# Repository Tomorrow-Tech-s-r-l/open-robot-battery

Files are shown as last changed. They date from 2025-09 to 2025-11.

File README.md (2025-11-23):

# ⚡ Open Robot Battery (ORB)

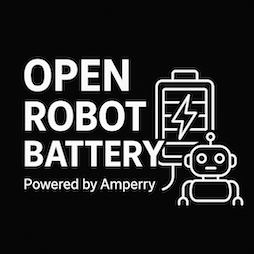
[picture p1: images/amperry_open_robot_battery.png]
Amperry Logo
 

*An open-source power delivery module for makers and robotics, powered by Amperry powerbanks.*

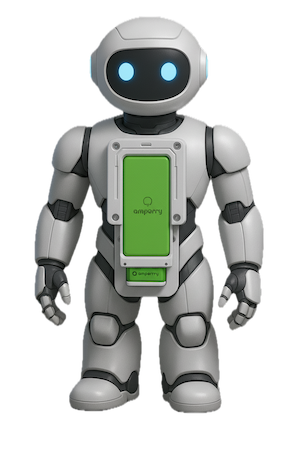
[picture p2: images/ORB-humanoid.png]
Humanoid Robot with ORB
  
*Humanoid robot powered by the ORB module.*

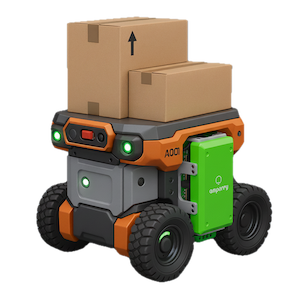
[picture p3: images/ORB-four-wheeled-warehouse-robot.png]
Four-wheeled Warehouse Robot with ORB
  
*Four-wheeled warehouse robot with ORB battery module.*

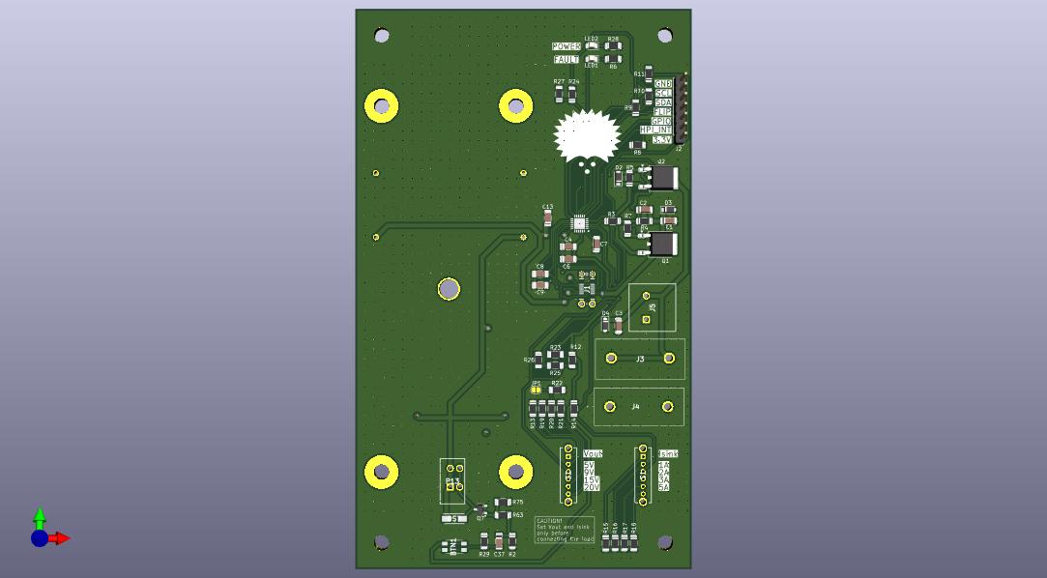
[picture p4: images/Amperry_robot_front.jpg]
Front PCB view
  
*Front PCB view.*

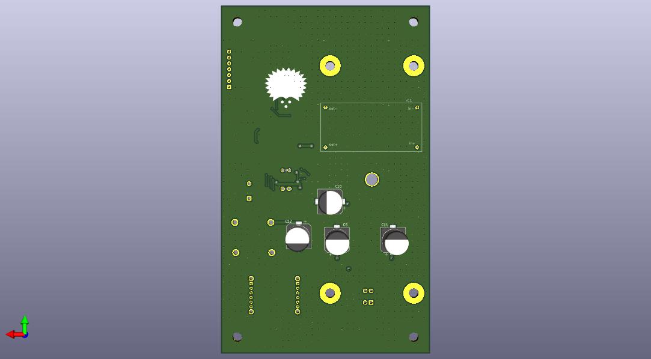
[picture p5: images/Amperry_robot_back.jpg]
Back PCB view
  
*Back PCB view.*

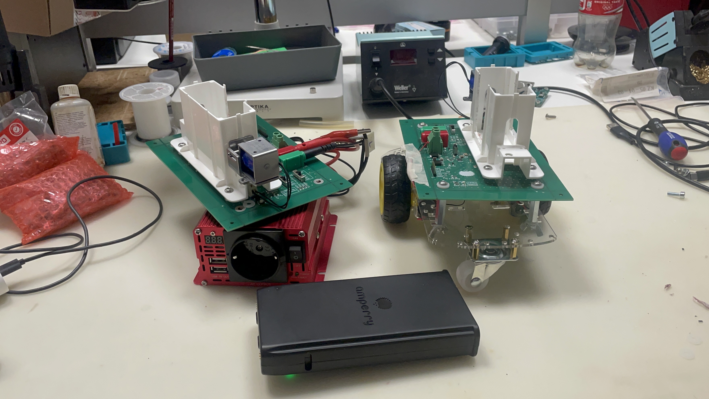
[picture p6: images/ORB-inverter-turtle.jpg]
ORB Inverter Turtle
  
*ORB inverter-turtle prototype with power inverter integration.*

ORB Development Kit  
*ORB development kit prototype for mobile robot applications.*

---

## 📖 Introduction

The **Open Robot Battery** (codename **ORB**) is an open-source hardware module designed to power up robots, IoT devices, drones, and prototypes.  

It works with **Amperry powerbanks**, which are charged inside Amperry stations, and provides makers, startups, and research labs with a flexible, safe, and modular way to bring portable energy into their projects.  

> ⚠️ **Important**: To use ORB you need an **Amperry-compatible powerbank**, which must be purchased together with an Amperry station. The ORB module is open-source, but the powerbanks remain proprietary.

---

## 🚀 Features

- ✅ Open hardware design for makers, startups, and research labs  
- ✅ Modular connection system (pogo pins, solenoid lock)  
- ✅ Flexible output: USB-C PD, robotics connectors (XT30/XT60), barrel jacks, etc.  
- ✅ Adaptable form factor – attach to robots, kiosks, IoT devices  
- ✅ Safe and tested with Amperry powerbanks  

---

## 🔌 How It Works
[ Amperry Station ] → [ Powerbank ] → [ ORB Module ] → [ Your Device ]

1. Powerbanks are charged inside the **Amperry station**.  
2. The charged powerbank is docked into the **ORB module**.  
3. ORB adapts the energy and delivers it to your device via your preferred connector.  

---

## 📦 Hardware Requirements

- **Required**: Amperry powerbank (purchase with a station from [Amperry](https://amperry.me))  
- Supported power levels:  
  - 5V (USB devices, IoT sensors)  
  - 12V (embedded boards, routers)  
  - 20V (robots, laptops, drones)  
- Connectors: USB-C PD, XT60, barrel jack, GPIO headers (customizable)  

---

## 🛠 Getting Started

1. Order an **Amperry powerbank + station**.  
2. Clone/download this repository.  
3. Access the **hardware files** in the `hardware/` folder:
   - Review the **schematics** (`hardware/schematics/LANDER_schematics.pdf`)
   - Check the **BOM** (`hardware/bom/LANDER_BOM.csv`) for component sourcing
   - Download **gerber files** (`hardware/gerber/LANDER-gerber-files.zip`) for PCB manufacturing
   - Use **CAD files** (`hardware/cad/LANDER_project_311025.zip`) for mechanical design and KiCad source files
4. Build or 3D-print the ORB module.  
5. Add the connectors your project requires.  
6. Plug in your powerbank and start powering your device.

## 🔧 Using with KiCad

The ORB project includes complete KiCad source files for both schematics and PCB layout. Follow these steps to open and work with the project in KiCad:

### Opening the KiCad Project

1. **Extract the CAD files**:
   ```bash
   cd hardware/cad
   unzip LANDER_project_311025.zip
   ```

2. **Open in KiCad**:
   - Launch KiCad (version 8.0 or later recommended)
   - Go to **File → Open Project**
   - Navigate to the extracted folder and open `Amperry_robot.kicad_pro`

3. **Project Structure**:
   The KiCad project contains:
   - `Amperry_robot.kicad_sch` - Main schematic file
   - `inputs_sheet.kicad_sch` - Input section schematic
   - `mech_conn_sheet.kicad_sch` - Mechanical connector section schematic
   - `Amperry_robot.kicad_pcb` - PCB layout file

### Viewing Schematics

- Click **Open Schematic** (or press `Ctrl+E`) to view the electrical schematics
- The project uses hierarchical sheets - navigate between sheets using the **Hierarchy Navigator** (press `Ctrl+H`)
- Use the **Properties** panel (press `E` on a component) to view component details

### Viewing PCB Layout

- Click **Open PCB Editor** (or press `Ctrl+P`) to view the PCB layout
- Use **3D Viewer** (press `Alt+3`) to see a 3D visualization of the board
- Switch between front and back layers using the layer selector

### Making Modifications

1. **Before making changes**, create a new branch or fork the repository
2. **Modify schematics** as needed:
   - Add/remove components
   - Adjust component values
   - Modify connections
3. **Update PCB layout** if schematic changes affect the board:
   - Run **Tools → Update PCB from Schematic** (or press `F8`) to sync changes
   - Adjust component placement and routing as needed
4. **Generate new Gerber files**:
   - Go to **File → Fabrication Outputs → Gerbers**
   - Select all layers and click **Generate Drill Files**
   - Export files for manufacturing

### Exporting for Manufacturing

1. **Generate Gerbers**:
   - File → Fabrication Outputs → Gerbers
   - Ensure all layers are selected (F.Cu, B.Cu, F.Silkscreen, B.Silkscreen, F.Mask, B.Mask, Edge.Cuts)
   - Generate drill files (PTH and NPTH)

2. **Generate BOM**:
   - File → Fabrication Outputs → BOM
   - Export as CSV or use the built-in BOM tool

3. **Create 3D Model**:
   - File → Export → STEP
   - Useful for mechanical integration

### Tips for Contributors

- Always run **Electrical Rules Check** (ERC) before committing changes (Tools → ERC)
- Run **Design Rules Check** (DRC) for PCB changes (Tools → DRC)
- Keep component libraries updated
- Document any significant changes in commit messages
- Test schematic changes by regenerating and reviewing the PDF export

## 📋 Documentation

- **[Technical Manual](MANUAL.md)** - Complete technical documentation including assembly instructions, safety warnings, and usage guidelines
- **[Hardware Files](hardware/)** - All hardware design files organized by type:
  - **[Schematics](hardware/schematics/)** - Electrical schematics in PDF format
  - **[Gerber Files](hardware/gerber/)** - PCB manufacturing files
  - **[Bill of Materials](hardware/bom/)** - Complete BOM in CSV format
  - **[CAD Files](hardware/cad/)** - KiCad source files (.kicad_sch, .kicad_pcb), 3D mechanical models (STEP), and Gerber files
  - **[Images](images/)** - Project images and diagrams  

---

## 💡 Example Use Cases

- 🤖 Robotics platforms and mobile robots  
- 🚁 Drones and UAVs  
- 🌐 IoT devices and field instruments  
- 🏫 University labs and prototyping kits  
- 🖥 Portable kiosks and installations  

---

## 📜 License & Usage Rules

- ORB is released as **open-source hardware** (license: [CC BY-NC-SA]).  
- **Restrictions**:  
  - The **Amperry powerbank hardware is proprietary** and must be purchased from Amperry.  
  - Usage in **powerbank rental systems** is exclusive to Amperry.  
  - Usage in **defense or weapons applications** requires prior approval and a special license.  

- For complete license details, see [LICENSE.md](LICENSE.md).
---

## 🤝 Contributing

We welcome contributions from the community! Here's how you can help improve the Open Robot Battery project.

### How to Contribute

1. **Report Issues**:
   - Found a bug or have a suggestion? Open an issue on GitHub
   - Include as much detail as possible: steps to reproduce, expected vs actual behavior, relevant files

2. **Improve Documentation**:
   - Fix typos or clarify instructions
   - Add missing information or examples
   - Translate documentation to other languages
   - Improve code comments and docstrings

3. **Hardware Improvements**:
   - **KiCad Project**: Modify schematics or PCB layout using the provided KiCad files
     - Extract the CAD files from `hardware/cad/LANDER_project_REV_DATE.zip` to work on them
     - Make changes in a new branch
     - Run ERC (Electrical Rules Check) and DRC (Design Rules Check) before submitting
     - Export updated Gerber files and update the repository
     - **Before committing**: Re-zip the CAD project folder and delete the unzipped folder
       ```bash
       cd hardware/cad
       zip -r LANDER_project_REV_DATE.zip [extracted_folder_name]/
       rm -rf [extracted_folder_name]/
       ```
     - Only commit the `.zip` file, not the extracted project files
     - This keeps the repository clean and prevents versioning conflicts with KiCad temporary files
   - **Mechanical Design**: Improve casing, mounting options, or add new connector configurations
   - **Component Selection**: Suggest better components or alternatives in the BOM

4. **Submit Pull Requests**:
   - Fork the repository
   - Create a feature branch (`git checkout -b feature/amazing-feature`)
   - Make your changes and test thoroughly
   - Commit with clear messages (`git commit -m 'Add amazing feature'`)
   - Push to your fork (`git push origin feature/amazing-feature`)
   - Open a Pull Request with a clear description of changes

### Contribution Guidelines

- **Code/Hardware Changes**:
  - Follow existing project structure and naming conventions
  - Ensure all tests pass (if applicable)
  - Update documentation for any new features
  - Run ERC/DRC checks for KiCad changes

- **Documentation**:
  - Use clear, concise language
  - Include examples where helpful
  - Update the README if adding new features

- **Pull Request Process**:
  - Keep PRs focused on a single feature or fix
  - Reference related issues in your PR description
  - Be responsive to feedback and requested changes

### Areas Where We Need Help

- 🐛 **Bug Fixes**: Test the design and report any issues
- 🔌 **New Connectors**: Add support for additional connector types
- 📐 **Mechanical Designs**: Improve casing, mounting solutions, or create 3D printable parts
- 🌍 **Translations**: Translate documentation to other languages
- 📚 **Examples**: Create example projects and use cases
- 🔬 **Testing**: Test designs with different powerbanks and report results

### Share Your Projects

We love seeing what people build with ORB! Share your projects:
- Open an issue with photos and description
- Tag us on social media
- Contribute to the gallery section

Thank you for contributing to open-source hardware! 🎉  

---

## 🌍 Community & Contact

- 🌐 Website: [https://tomorrowtech.it/open-robot-battery.html](https://amperry.me)  
- ✉️ Email: sviluppo@tomorrowtech.it  

---

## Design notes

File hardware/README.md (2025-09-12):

# Hardware Design Files

This folder contains all the hardware design files for the **LANDER** module (Open Robot Battery), organized for easy access and reproduction.

## 📁 Folder Structure

```
hardware/
├── schematics/          # Electrical schematics and circuit diagrams
├── gerber/             # PCB manufacturing files
├── bom/                # Bill of Materials (component lists)
├── cad/                # 3D mechanical models and CAD files
└── images/             # Project images and diagrams
```

## 📋 File Types

### Schematics (`schematics/`)
- **LANDER-schematics.pdf** - Complete electrical circuit diagrams for the LANDER module
- **Source files** - Original schematic files (KiCad, Altium, etc.)

### Manufacturing Files (`gerber/`)
- **LANDER-gerber-files.zip** - PCB manufacturing files for LANDER module fabrication
- **Drill files** - Hole drilling specifications
- **Panel files** - Multi-board panels for automated assembly

### Bill of Materials (`bom/`)
- **LANDER-BOM.xlsx** - Complete component list with part numbers and suppliers
- **LANDER-BOM.csv** - Machine-readable format for import into other systems

### CAD Files (`cad/`)
- **LANDER-CAD-files.zip** - Complete mechanical design package
- **3D Models** - Mechanical design files (STEP, STL)
- **Source CAD** - Original design files (SolidWorks, Fusion 360, etc.)

### Images (`images/`)
- **Project photos** - Assembly and usage images
- **Diagrams** - Technical illustrations and block diagrams

## 🛠 Manufacturing Notes

- **PCB Thickness**: 1.6mm
- **Copper Weight**: 1oz
- **Surface Finish**: HASL or ENIG recommended
- **Solder Mask**: Green (standard)
- **Silkscreen**: White

## 📦 Component Sourcing

All components in the BOM are selected from major electronics distributors for:
- Easy sourcing and availability
- Competitive pricing
- Quality assurance
- Lead time reliability

## ⚠️ Important Notes

- This is a **proof-of-concept** design for laboratory use only
- Not certified for commercial applications
- Follow all safety guidelines in the technical manual
- Use proper ESD precautions when handling components

## 🔗 Related Documentation

- [Technical Manual](../MANUAL.md) - Complete assembly and usage instructions
- [Main README](../README.md) - Project overview and getting started guide

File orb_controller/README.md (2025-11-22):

# ORB Controller ROS Package

## Overview

The `orb_controller` package provides a ROS interface for controlling the Infineon EZ-PD BCR (CYPD3177) USB Type-C Port Controller via I2C. This package enables monitoring and control of USB Power Delivery (PD) negotiation for robotic battery management systems.

## Features

- **I2C Communication:** Direct hardware interface to EZ-PD BCR chip
- **Power Monitoring:** Real-time voltage, current, and power status
- **PD Control:** Request specific voltage profiles (5V, 9V, 12V, 15V, 20V)
- **Status Publishing:** Continuous monitoring via ROS topics
- **Service Interface:** On-demand control via ROS services
- **Safety Features:** Voltage/current limits and fault monitoring

## Hardware Requirements

- Infineon EZ-PD BCR (CYPD3177) chip
- I2C connection to host system
- USB Type-C connector with PD support
- Appropriate power source/sink capabilities

## Dependencies

### System Dependencies
```bash
sudo apt-get install -y \
    i2c-tools \
    libi2c-dev \
    python3-smbus
```

### ROS Dependencies
- ROS Noetic (or compatible version)
- roscpp
- std_msgs
- message_generation
- message_runtime

## Installation

1. Clone the repository to your catkin workspace:
```bash
cd ~/catkin_ws/src
git clone <repository-url>
```

2. Build the package:
```bash
cd ~/catkin_ws
catkin_make
source devel/setup.bash
```

3. Configure I2C permissions (if needed):
```bash
sudo usermod -a -G i2c $USER
# Log out and back in for changes to take effect
```

## Usage

### Launch the Controller Node

Basic launch:
```bash
roslaunch orb_controller orb_controller.launch
```

With custom parameters:
```bash
roslaunch orb_controller orb_controller.launch i2c_bus:=1 i2c_address:=0x08 publish_rate:=10.0
```

### Published Topics

- `/orb/power_status` ([orb_controller/PowerStatus])
  - Real-time power measurements
  - Published at configured rate (default: 10 Hz)

- `/orb/pd_status` ([orb_controller/PDStatus])
  - USB-C PD negotiation status
  - Published at configured rate (default: 10 Hz)

### Services

- `/orb_controller/get_status` ([orb_controller/GetStatus])
  - Get current voltage, current, and PD status

- `/orb_controller/set_voltage_current` ([orb_controller/SetVoltageCurrent])
  - Request specific voltage and current limits

- `/orb_controller/request_pd_role` ([orb_controller/RequestPDRole])
  - Request specific PD profile (1-5)

### Parameters

Configuration parameters can be set in `config/orb_controller_params.yaml`:

- `i2c_bus`: I2C bus number (default: 1)
- `i2c_address`: I2C device address (default: 0x08)
- `publish_rate`: Status publishing rate in Hz (default: 10.0)
- `max_voltage_mv`: Maximum allowed voltage in mV (default: 20000)
- `max_current_ma`: Maximum allowed current in mA (default: 5000)

## Testing

### ROS Test Script
```bash
rosrun orb_controller test_orb_controller.py
```

Monitor mode:
```bash
rosrun orb_controller test_orb_controller.py monitor
```

### Direct I2C Test (bypasses ROS)
```bash
# Basic test
python3 scripts/test_i2c_direct.py

# Custom bus and address
python3 scripts/test_i2c_direct.py --bus 1 --addr 0x08

# Scan all registers
python3 scripts/test_i2c_direct.py --scan

# Monitor for 30 seconds
python3 scripts/test_i2c_direct.py --monitor 30
```

## Examples

### Request 12V Profile
```bash
rosservice call /orb_controller/request_pd_role "profile: 3"
```

### Set Specific Voltage and Current
```bash
rosservice call /orb_controller/set_voltage_current "voltage_mv: 9000
current_ma: 2000"
```

### Get Current Status
```bash
rosservice call /orb_controller/get_status
```

### Monitor Power Status
```bash
rostopic echo /orb/power_status
```

## Message Definitions

### PowerStatus.msg
```
std_msgs/Header header
uint16 voltage_mv        # Voltage in millivolts
uint16 current_ma        # Current in milliamps
uint32 power_mw          # Power in milliwatts
bool pd_active           # PD negotiation active
uint8 pd_profile         # Current PD profile (1-5)
```

### PDStatus.msg
```
std_msgs/Header header
uint8 pd_status_raw      # Raw PD status byte
uint8 port_status_raw    # Raw port status byte
bool type_c_connected    # USB-C cable connected
bool pd_contract_active  # PD contract established
uint8 current_profile    # Active profile number
uint16 negotiated_voltage_mv  # Negotiated voltage
uint16 negotiated_current_ma  # Negotiated current
```

## Troubleshooting

### I2C Connection Issues
```bash
# Check if I2C device is detected
i2cdetect -y 1

# Verify I2C permissions
ls -l /dev/i2c-*

# Test I2C communication
i2cget -y 1 0x08 0x00
```

### Node Not Starting
- Check ROS master is running: `roscore`
- Verify I2C device permissions
- Check correct I2C bus and address in parameters
- Review log output: `rosrun orb_controller orb_controller_node`

### No Power Delivery
- Verify USB-C cable supports PD
- Check power source capabilities
- Monitor PD status: `rostopic echo /orb/pd_status`
- Review fault status in logs

## Register Documentation

See [docs/REGISTER_MAP.md](docs/REGISTER_MAP.md) for detailed register descriptions and bit definitions.

**Important:** The register addresses in this package are based on typical EZ-PD BCR implementations. You must verify these with your specific CYPD3177 datasheet and update the following files accordingly:
- `include/orb_controller/ezpd_bcr_i2c.h` - Register address definitions
- `src/ezpd_bcr_i2c.cpp` - Register access implementations
- `src/orb_controller_node.cpp` - Status bit interpretations

## Safety Notes

⚠️ **WARNING:** Improper voltage/current settings can damage connected devices.

- Always verify device voltage tolerances before changing profiles
- Monitor fault status regularly
- Implement appropriate error handling in production code
- Test with current-limited supplies during development
- Never exceed maximum ratings specified in datasheets

## License

This package is released under the CC-BY-NC-SA license as specified in the package.xml file.

## Support

For issues and questions, please contact: sviluppo@tomorrowtech.it

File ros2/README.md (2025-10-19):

# ORB ROS 2 Workspace

This directory contains the ROS 2 workspace that hosts software support for the Open Robot Battery (ORB).

## Packages

- `orb_i2c_interfaces`: Service definitions shared across the I2C stack.
- `orb_i2c_support`: Python implementation of the I2C management node with a pluggable backend, including both a simulation layer and a driver for the Infineon EZ-PD BCR USB-C sink controller.

## Building

```bash
cd ros2
colcon build
source install/setup.bash
```

> If you only want to build the packages added here, append `--packages-up-to orb_i2c_support`.

## Running the I2C manager

```bash
ros2 launch orb_i2c_support i2c_manager.launch.py
```

By default the node runs in simulation mode. All transactions are served from an in-memory backend that mimics a trivial I2C device.

### Useful Parameters

| Parameter | Default | Description |
|---|---|---|
| `backend` | `simulation` | Backend name registered in `orb_i2c_support.backend_factory`. |
| `bus_id` | `i2c-1` | Logical identifier for the I2C bus; forwarded to the backend. |
| `backend_plugin` | *empty* | Optional `module:ClassName` string to load a custom backend. |
| `backend_configuration` | `{}` | JSON configuration passed to the backend. |
| `status_interval_sec` | `1.0` | Interval in seconds for status publication on `orb_i2c/status`. |

Example launch overriding the backend configuration:

```bash
ros2 launch orb_i2c_support i2c_manager.launch.py \
  backend_configuration:='{"devices": [{"address": 16, "memory": [1, 2, 3]}]}'
```

### Calling the service

Once the node is running:

```bash
ros2 service call /i2c/transaction orb_i2c_interfaces/srv/I2CTransaction \
  "{address: 16, write_data: [170, 187], read_length: 4, timeout: 0.1}"
```

The response will contain the simulated read buffer. When the real hardware backend becomes available, drop it in as a plugin and reuse the same service interface.

### Using the EZ-PD BCR backend

The Infineon EZ-PD BCR controller exposes its register map over I2C. The provided backend wraps the Linux `smbus2` stack to perform combined write/read transactions and optional power-on configuration sequences.

```bash
ros2 launch orb_i2c_support i2c_manager.launch.py \
  backend:=ez_pd_bcr \
  bus_id:=/dev/i2c-1 \
  backend_configuration:='{
    "default_address": 8,
    "init_sequence": [
      {"write_data": [0x00, 0x08]},  # Example: pull default register map
      {"write_data": [0x06, 0x01], "delay_ms": 5}
    ]
  }'
```

- `default_address` (optional) overrides the default 7-bit address (`0x08` in the datasheet).
- `init_sequence` (optional) allows writing configuration registers at launch. Each entry contains `write_data` (first byte is treated as the register offset) and an optional `delay_ms` for settling time between writes.

Typical tasks enabled by this backend:
- Read the status registers that report VBUS negotiation state, CC pin status, and fault indicators.
- Update configuration registers to adjust PDO selection, discharge behavior, or the sink power profile.
- Trigger firmware utilities such as soft resets or load complete configuration templates as documented in the datasheet.

Example register read (fetch the Status Register 1 at offset `0x05`):

```bash
ros2 service call /i2c/transaction orb_i2c_interfaces/srv/I2CTransaction \
  "{address: 8, write_data: [0x05], read_length: 1, timeout: 0.1}"
```

The first byte in `write_data` is interpreted by the controller as the register pointer; the returned byte shows the live status flags defined in section 6.3 of the EZ-PD BCR datasheet.

### Standalone Raspberry Pi smoke test

If you want to validate the hardware before running ROS:

```bash
pip install smbus2
python3 ros2/scripts/raspi_ez_pd_demo.py
```

The script opens `/dev/i2c-1`, reads Status Register 1 once per second, and prints the bit field as a binary string. A changing value indicates the Pi can reach the EZ-PD BCR device over the I²C bus.

## Tests

Run the unit tests with:

```bash
colcon test --packages-select orb_i2c_support
```

> The test suite depends on `pytest`. Install it in your environment (e.g., `pip install pytest`) if it is not already available.

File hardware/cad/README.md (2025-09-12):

# CAD Files

This folder contains the mechanical design files for the Open Robot Battery (LANDER) project.

## Files

- `LANDER-CAD-files.zip` - Complete CAD package containing 3D mechanical models and source files for the LANDER module
- `LANDER-mechanical.step` - 3D mechanical model in STEP format [TODO]
- `LANDER-mechanical.stl` - 3D printable files for prototyping [TODO]

## Mechanical Features

- Powerbank docking mechanism
- Spring ejector system
- Solenoid mounting points
- Connector mounting areas
- Heat dissipation considerations

## 3D Printing

STL files are provided for rapid prototyping and testing of mechanical components.

> **Note**: Replace this README with actual CAD files when available.

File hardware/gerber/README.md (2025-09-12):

# Gerber Files

This folder contains the manufacturing files for the Open Robot Battery (LANDER) PCB.

## Files

- `LANDER-gerber-files.zip` - Complete gerber file package for LANDER module PCB manufacturing

## Manufacturing Notes

- Board thickness: 1.6mm
- Copper weight: 1oz
- Surface finish: HASL or ENIG (recommended)
- Solder mask: Green (standard)
- Silkscreen: White

## Panel Information

The gerber package includes both:
- Individual PCB files
- Panel files with V-score lines for automated assembly

> **Note**: Replace this README with actual gerber files when available.

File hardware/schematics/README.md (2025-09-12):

# Schematics

This folder contains the electrical schematics for the Open Robot Battery (LANDER) project.

## Files

- `LANDER-schematics.pdf` - Complete electrical schematics for the LANDER module in PDF format

## Schematic Overview

The main schematic includes:
- USB-C Power Delivery Controller (CYPD3177)
- Boost converter for solenoid power
- Powerbank mechanical docking system
- I2C interface connections
- Multiposition switches for voltage/current selection

> **Note**: Replace this README with actual schematic files when available.

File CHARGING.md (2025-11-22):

# Battery Charging Guide

## Overview

This guide explains the temporary procedure for charging the Open Robot Battery. **Note:** This is a temporary charging method. A proper charging circuit is currently being developed.

## Prerequisites

- Power supply capable of delivering 16.8V and 0.8A
- Access to the powerbank connector (requires unscrewing the powerbank)

## Charging Procedure

### Step 1: Access the Connector

1. **Unscrew the powerbank** to gain access to the internal connector.

### Step 2: Connect Power Supply

1. Connect your power supply to the battery connector.
2. **Set the power supply to:**
   - **Voltage:** 16.8V
   - **Current:** 0.8A

### Step 3: Charging

1. Once connected and configured, the battery will begin charging.
2. **Charging time:** Approximately 3 hours

### Step 4: Disconnect

1. After the charging cycle is complete, disconnect the power supply.
2. Reassemble the powerbank by screwing it back together.

## Important Notes

⚠️ **This is a temporary charging solution.** A dedicated charging circuit with proper power supply management is currently under development and will replace this manual procedure in the future.

## Safety Reminders

- Always ensure the power supply is set to the correct voltage (16.8V) and current (0.8A) before connecting.
- Do not exceed the specified voltage and current limits.
- Monitor the charging process and disconnect if any abnormalities are observed.

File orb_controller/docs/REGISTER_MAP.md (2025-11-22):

# EZ-PD BCR (CYPD3177) Register Map Documentation

## Overview
This document describes the I2C register map for the Infineon EZ-PD BCR (CYPD3177) USB Type-C Port Controller.

**NOTE:** The register addresses and bit definitions below are based on typical EZ-PD BCR implementations. 
You should verify these with the actual CYPD3177 datasheet for your specific chip revision.

## I2C Interface Details

- **Default I2C Address:** 0x08 (can be modified via ADDR pins)
- **I2C Speed:** Standard mode (100 kHz) or Fast mode (400 kHz)
- **Data Format:** Big-endian for multi-byte registers

## Register Map

### Device Information Registers (0x00-0x0F)

| Address | Register Name | Access | Description |
|---|---|---|---|
| 0x00 | DEVICE_ID | R | Device identification |
| 0x01 | DEVICE_MODE | R/W | Device operation mode |
| 0x02 | INTERRUPT_CLEAR | W | Clear interrupt flags |
| 0x03 | INTERRUPT_MASK | R/W | Interrupt enable mask |
| 0x04 | PD_STATUS | R | Power Delivery status |
| 0x05 | TYPE_C_STATUS | R | USB Type-C connection status |
| 0x06-0x07 | BUS_VOLTAGE | R | VBUS voltage (16-bit) |
| 0x08-0x09 | CURRENT_PDO | R | Current Power Data Object |
| 0x0A-0x0B | VOLTAGE_STATUS | R | Negotiated voltage (16-bit) |
| 0x0C-0x0D | CURRENT_STATUS | R | Negotiated current (16-bit) |
| 0x0E | POWER_STATUS | R | Power status summary |
| 0x0F | FAULT_STATUS | R | Fault status flags |

### Control Registers (0x10-0x1F)

| Address | Register Name | Access | Description |
|---|---|---|---|
| 0x10 | PD_CONTROL | R/W | PD control and profile selection |
| 0x11 | PORT_CONTROL | R/W | Port enable/disable control |
| 0x12 | VBUS_CONTROL | R/W | VBUS control settings |
| 0x13 | CURRENT_LIMIT | R/W | Current limit configuration |
| 0x14-0x15 | VOLTAGE_REQUEST | R/W | Requested voltage (16-bit) |
| 0x16-0x17 | CURRENT_REQUEST | R/W | Requested current (16-bit) |
| 0x18 | SINK_CONTROL | R/W | Sink operation control |
| 0x19 | SOURCE_CONTROL | R/W | Source operation control |
| 0x1A | CABLE_DETECT | R | Cable detection status |
| 0x1B-0x1F | RESERVED | - | Reserved for future use |

### PDO Configuration Registers (0x20-0x3F)

| Address | Register Name | Access | Description |
|---|---|---|---|
| 0x20-0x23 | SINK_PDO_1 | R/W | Sink PDO #1 (5V profile) |
| 0x24-0x27 | SINK_PDO_2 | R/W | Sink PDO #2 (9V profile) |
| 0x28-0x2B | SINK_PDO_3 | R/W | Sink PDO #3 (12V profile) |
| 0x2C-0x2F | SINK_PDO_4 | R/W | Sink PDO #4 (15V profile) |
| 0x30-0x33 | SINK_PDO_5 | R/W | Sink PDO #5 (20V profile) |
| 0x34-0x37 | SINK_PDO_6 | R/W | Sink PDO #6 (PPS profile) |
| 0x38-0x3F | RESERVED | - | Reserved |

## Register Bit Definitions

### PD_STATUS Register (0x04)

| Bit | Name | Description |
|-----|---|---|
| 7 | PD_READY | PD negotiation complete |
| 6 | CONTRACT_EXIST | Valid PD contract exists |
| 5 | EXPLICIT_CONTRACT | Explicit contract negotiated |
| 4 | DATA_ROLE | 0=UFP, 1=DFP |
| 3 | POWER_ROLE | 0=Sink, 1=Source |
| 2 | VCONN_SOURCE | Device is VCONN source |
| 1 | PD_ENABLED | PD messaging enabled |
| 0 | PD_CONNECTED | PD capable device connected |

### TYPE_C_STATUS Register (0x05)

| Bit | Name | Description |
|-----|---|---|
| 7:6 | ATTACH_STATE | 00=Unattached, 01=AttachWait, 10=Attached, 11=Debug |
| 5 | ORIENTATION | 0=CC1, 1=CC2 |
| 4 | VBUS_PRESENT | VBUS voltage detected |
| 3 | VBUS_VALID | VBUS voltage in valid range |
| 2 | VCONN_PRESENT | VCONN supplied to cable |
| 1 | CC_STATUS | CC line status |
| 0 | CONNECTED | Cable connected |

### PD_CONTROL Register (0x10)

| Bit | Name | Description |
|-----|---|---|
| 7:5 | RESERVED | Reserved |
| 4:0 | PROFILE_SELECT | Select PDO profile (1-5) |

### FAULT_STATUS Register (0x0F)

| Bit | Name | Description |
|-----|---|---|
| 7 | OCP | Over-current protection triggered |
| 6 | OVP | Over-voltage protection triggered |
| 5 | OTP | Over-temperature protection triggered |
| 4 | VBUS_SHORT | VBUS short circuit detected |
| 3 | VCONN_OCP | VCONN over-current |
| 2 | HARD_RESET | Hard reset occurred |
| 1 | SOFT_RESET | Soft reset occurred |
| 0 | GENERAL_FAULT | General fault condition |

## Voltage and Current Scaling

### Voltage Registers
- **Unit:** 50mV per LSB
- **Range:** 0-20V (0x0000-0x0190)
- **Example:** 0x64 = 100 * 50mV = 5000mV = 5V

### Current Registers
- **Unit:** 10mA per LSB for standard current
- **Unit:** 50mA per LSB for high current (>3A)
- **Range:** 0-5A (0x0000-0x01F4)
- **Example:** 0xC8 = 200 * 10mA = 2000mA = 2A

## Standard PDO Profiles

| Profile | Voltage | Max Current | Power |
|---|---|---|---|
| 1 | 5V | 3A | 15W |
| 2 | 9V | 3A | 27W |
| 3 | 12V | 3A | 36W |
| 4 | 15V | 3A | 45W |
| 5 | 20V | 5A | 100W |

## I2C Transaction Examples

### Read Voltage Status
```
Write: [0x0A]       // Register address
Read:  [MSB] [LSB]  // 16-bit voltage value
```

### Set PD Profile
```
Write: [0x10] [0x03]  // Write 0x03 to PD_CONTROL for 12V profile
```

### Read PD Status
```
Write: [0x04]       // Register address
Read:  [Status]     // 8-bit status value
```

## Notes

1. Always verify register addresses and bit definitions with the actual CYPD3177 datasheet
2. Some registers may require specific sequences or timing for proper operation
3. Writing to read-only registers will be ignored
4. Some control registers may require device to be in specific state
5. Multi-byte registers typically use big-endian format, but verify with datasheet

## Safety Considerations

- Always check voltage and current capabilities before requesting higher profiles
- Monitor fault status register regularly
- Implement proper error handling for I2C communication failures
- Use appropriate delays between configuration changes
- Verify cable and device capabilities before negotiating high power profiles

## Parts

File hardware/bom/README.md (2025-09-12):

# Bill of Materials (BOM)

This folder contains the Bill of Materials for the Open Robot Battery (LANDER) project.

## Files

- `LANDER-BOM.xlsx` - Complete Bill of Materials for the LANDER module in Excel format with part numbers, quantities, and suppliers

## Key Components

### Main Components
- **CYPD3177** - USB-C Power Delivery Controller
- **Boost Converter** - For solenoid power supply
- **Solenoid** - Powerbank ejection mechanism
- **USB-C Connector** - Power input/output
- **Multiposition Switches** - Voltage/current selection

### Passive Components
- Resistors and capacitors for power management
- Connectors and headers for I2C interface
- Mechanical components for powerbank docking

## Sourcing Notes

All components are selected from major electronics distributors for easy sourcing and availability.

> **Note**: Replace this README with actual BOM files when available.

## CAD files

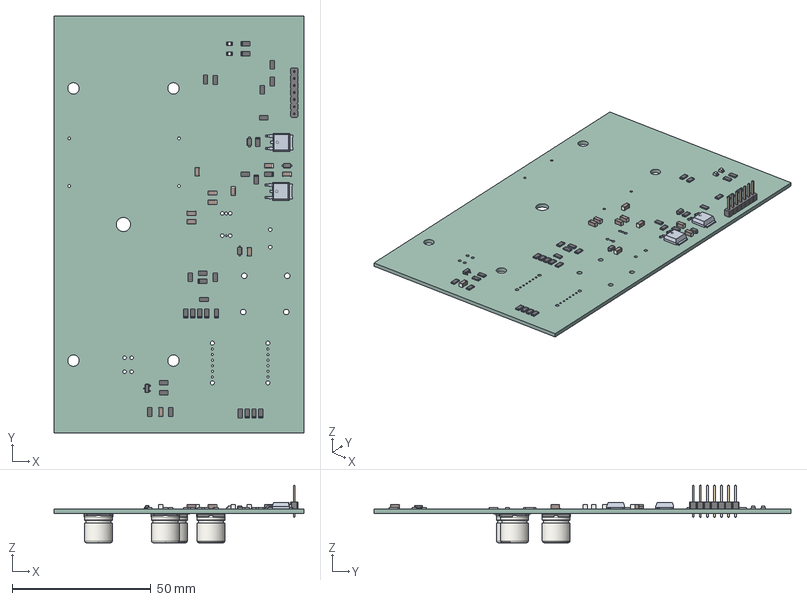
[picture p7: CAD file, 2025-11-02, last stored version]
hardware/cad/LANDER_project_311025/gerbers/Amperry_robot.step
90.0 x 150.0 x 20.7 mm
R_1206_3216Metric x 30
Amperry_robot 1.4.1 x 2
LED_0805_2012Metric x 2
D_SOD-123F x 3
C_1206_3216Metric x 10
PinHeader_1x07_P2.54mm_Vertical
SOT-23-3
CP_Elec_10x10.5 x 4
Amperry_robot_PCB

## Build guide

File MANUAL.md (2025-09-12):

# Open Robot Battery - Technical Manual

## Purpose of the Board

The purpose of this PCB is to provide a proof-of-concept (POC) charging solution for generic devices using a USB-C interface. The board is intended for laboratory and demonstration purposes, providing:

- Safe charging of low-power devices from a standardized USB-C port
- Flexibility to adapt to various input and output power requirements
- A compact design to fit within an existing powerbank slot

> **⚠️ Important**: This board is not certified for commercial use and is designed for internal testing, demonstration, and prototyping only.

## Main Function Blocks

| Block | Description | Key Components |
|---|---|---|
| **USB-C Power Delivery Controller** | This is the core of the board. It manages USB-C negotiation and ensures correct voltage/current delivery to the connected device. | CYPD3177, associated resistors and capacitors, controllable by the multiposition switches |
| **Boost Module** | Converts and regulates the input voltage from the powerbank to 24V for the coil solenoid | Boost converter |
| **Powerbank Mechanical Docking** | Provides mechanical and electrical connection for the powerbank | Spring ejector, coil solenoid, USB C connector* |
| **I2C Interface** | To access status and control register | Pin strip connection |

> *Only for the POC, the future release will be different

## How It Works

### Power Input
- The board receives voltage from the connected powerbank
- The board is designed to be compatible with the Amperry powerbank that supports USB-C PD up to 20V

### USB-C Negotiation
- The CYPD3177 acts as the USB-C controller
- The controller negotiates the required voltage/current with the powerbank

### Voltage/Current Regulation and Output Delivery
There are 2 multiposition switches (SW1 and SW2) that allow the user to select some resistor combinations that set the output voltage and current limit.

> **⚠️ Important**: The output voltage (V) and current limit (I) must be set through the switch before connecting the load. The mechanical switch can temporarily disconnect the resistive load when moving from one position to another; during this brief interval, the output voltage automatically rises to the maximum available voltage (20V). Connecting a load before setting V/I can damage the device.

### Powerbank Ejection
- The board contains a boost converter that raises the supply to 24V for the solenoid
- When the push-button is pressed, the solenoid coil is energized, pulling a plunger
- The mechanical spring then ejects the powerbank from its slot
- To ensure that the coil solenoid stays active only for a short time enough to unlock the powerbank (even if the button is pressed for a long time) there is an ad hoc RC filter
- The solenoid is de-energized after the ejection cycle

## Assembly Instructions

This project package includes two main items:
- **Individual PCB** – the proof-of-concept board for multidevice recharge
- **PCB Panel** – a larger panel containing multiple copies of the board, separated by V-score lines, designed to facilitate automatic component placement during production

### Hardware Files Location

All hardware design files are organized in the `hardware/` folder:
- **Schematics**: `hardware/schematics/LANDER-schematics.pdf`
- **Gerber Files**: `hardware/gerber/LANDER-gerber-files.zip`
- **Bill of Materials**: `hardware/bom/LANDER-BOM.xlsx`
- **CAD Files**: `hardware/cad/LANDER-CAD-files.zip`

### Component Assembly
- All components were selected from major electronics distributors for easy sourcing (see BOM in `hardware/bom/`)
- **Manual soldering**: Most components, including resistors, capacitors, connectors, and the boost converter, can be soldered by hand without specialized equipment
- **CYPD3177**: This IC requires careful soldering due to its fine pitch; automated reflow or precision soldering is recommended

### Assembly Steps
1. Detach the individual PCB from the V-scored panel along the designated lines
2. Populate components starting with the lowest profile parts (resistors, capacitors), followed by connectors and the boost converter
3. Place the CYPD3177 last, using appropriate soldering techniques to ensure proper alignment and connection
4. Inspect all solder joints for bridges or cold soldering, paying special attention to the USB-C controller and high-current paths

## Testing

1. Before connecting a load, set the output voltage and current using SW1 and SW2
2. Apply power from a compatible USB-C power source
3. Verify correct voltage at the output terminals with a multimeter
4. Test the powerbank ejection mechanism without a load first to ensure the solenoid operates correctly
5. Once verified, the board is ready for controlled laboratory use with target devices

## Safety Warnings

> **⚠️ Important**: This board is a proof-of-concept prototype intended for controlled laboratory use only. It is not certified for commercial or consumer applications.

### Electrical Safety

- **Voltage spikes**: When changing the output voltage/current with the switches, the board may briefly output the maximum available voltage (~20 V). Always set the desired V/I before connecting a load
- **Risk of damage**: Connecting devices before setting the correct voltage/current may damage the load or the board
- **High-current paths**: The solenoid and boost converter can draw significant current. Avoid touching exposed conductors during operation
- **Short circuits**: Do not short the output terminals. This can damage the board and connected power sources

### Mechanical Safety

- The board contains a spring-eject mechanism and solenoid. Do not place fingers or objects near the moving parts during testing to prevent pinching or injury
- Ensure the board is securely mounted on a stable surface during testing

### Component Handling

- The CYPD3177 and other ICs are sensitive to ESD. Use proper anti-static precautions (wrist strap, ESD mat) when handling
- Soldering should be performed in a well-ventilated area. Avoid inhaling solder fumes

### Usage Limitations

- The board is designed for low-power devices only. Do not connect high-power or commercial devices
- **Environmental conditions**: Operate only in dry, controlled laboratory environments. Avoid exposure to water, high humidity, or uncontrolled loads
- No CE, EMC, or other certifications are included. Users are responsible for ensuring safe lab practices

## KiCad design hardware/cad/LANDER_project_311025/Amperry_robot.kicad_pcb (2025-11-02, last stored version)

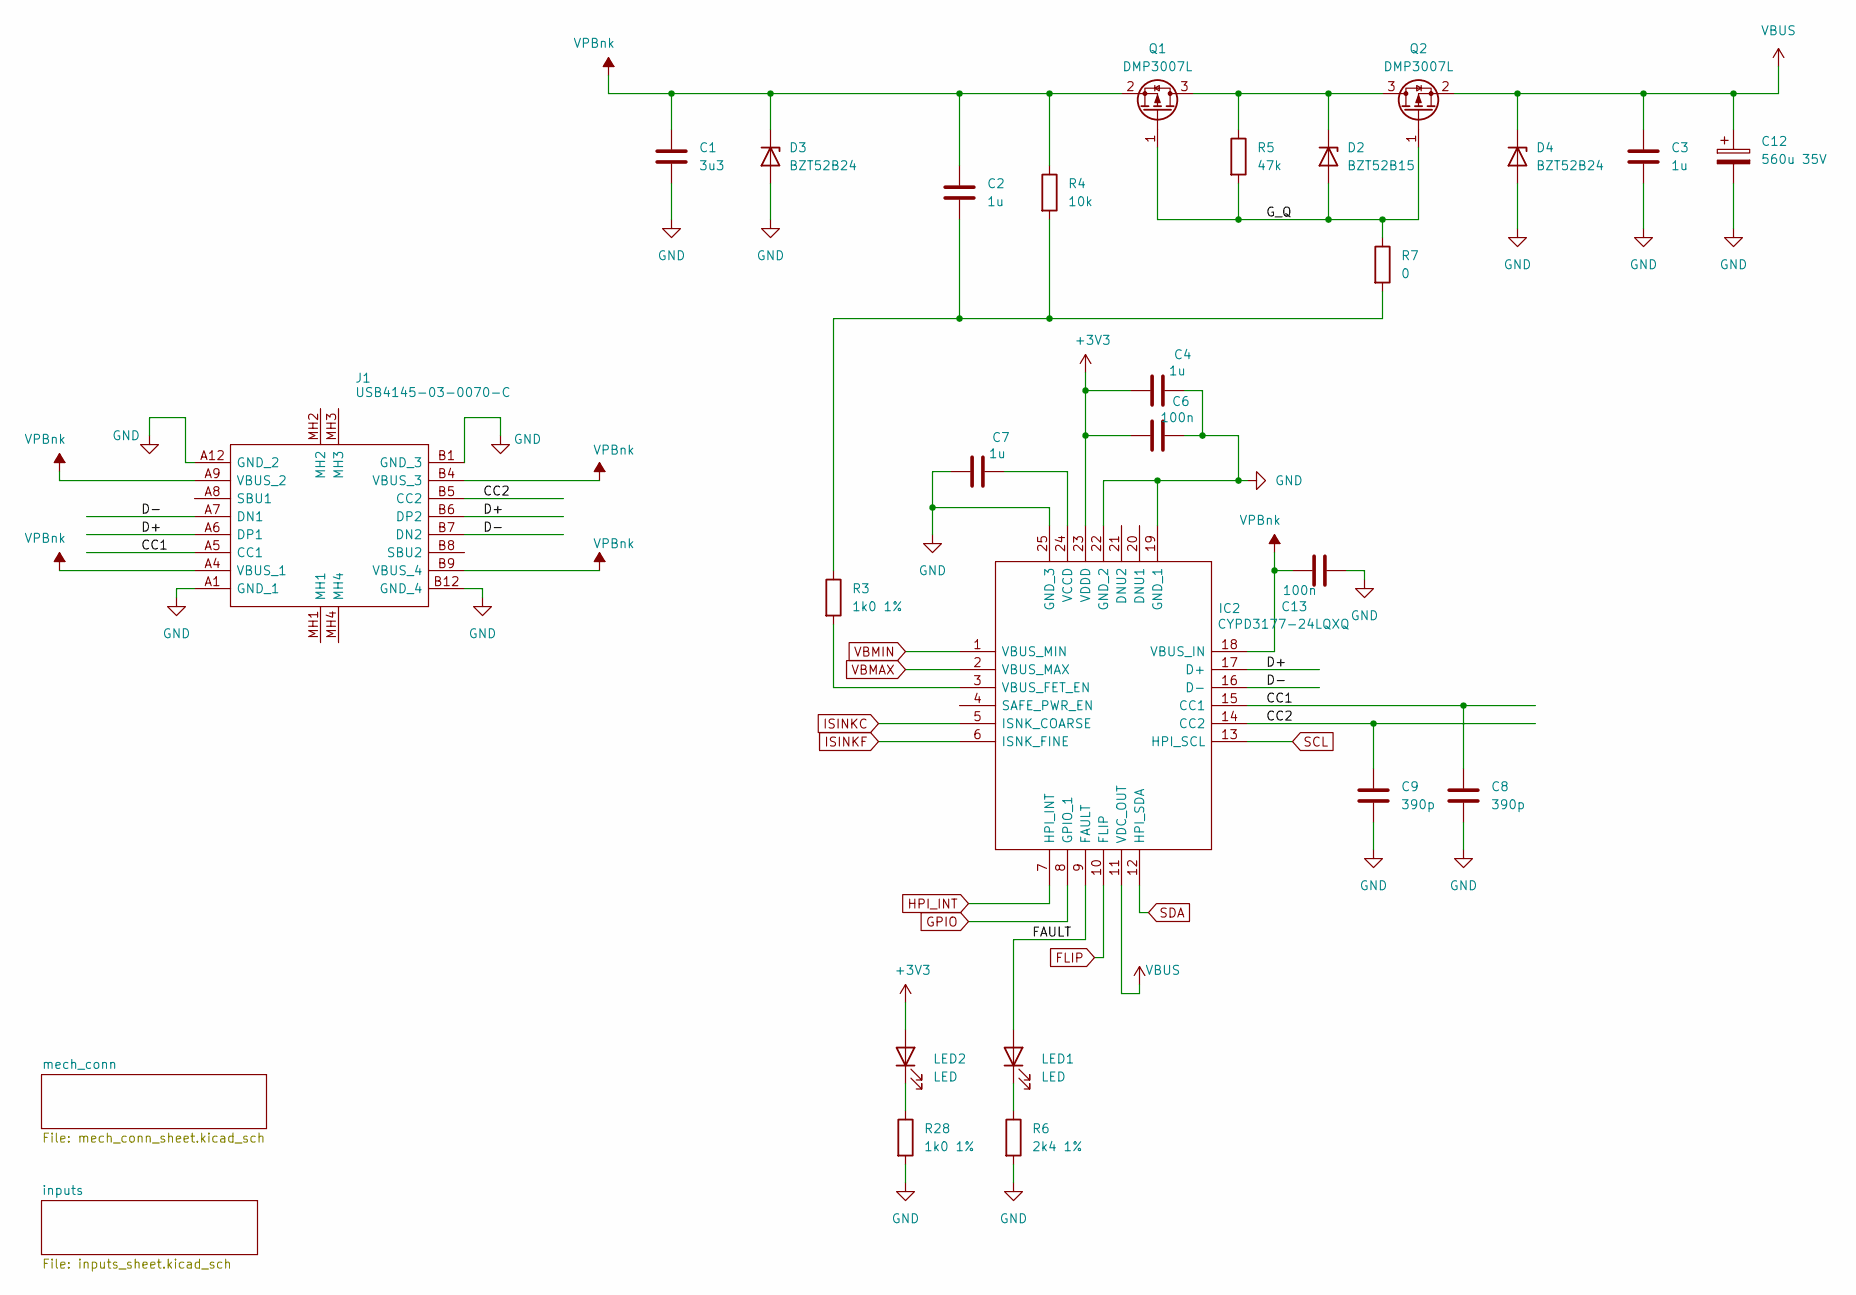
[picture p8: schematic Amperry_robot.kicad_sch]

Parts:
C1: 3u3; C_1206_3216Metric_Pad1.33x1.80mm_HandSolder
C2, C3, C4, C7: 1u; C_1206_3216Metric_Pad1.33x1.80mm_HandSolder
C6, C13: 100n; C_1206_3216Metric_Pad1.33x1.80mm_HandSolder
C8, C9: 390p; C_1206_3216Metric_Pad1.33x1.80mm_HandSolder
C12: 560u 35V; CP_Elec_10x10.5
D2: BZT52B15; D_SOD-123F
D3, D4: BZT52B24; D_SOD-123F
IC2: CYPD3177-24LQXQ; QFN50P400X400X60-25N-D; Manufacturer_Part_Number CYPD3177-24LQXQ; Mouser Part Number 727-CYPD3177-24LQXQ
J1: USB4145-03-0070-C; USB4145030070C; Manufacturer_Part_Number USB4145-03-0070-C; Mouser Part Number 640-USB4145-3-0070-C
LED1, LED2: LED; LED_0805_2012Metric_Pad1.15x1.40mm_HandSolder
Q1, Q2: DMP3007L; TO-252-2
R3, R28: 1k0 1%; R_1206_3216Metric_Pad1.30x1.75mm_HandSolder
R4: 10k; R_1206_3216Metric_Pad1.30x1.75mm_HandSolder
R5: 47k; R_1206_3216Metric_Pad1.30x1.75mm_HandSolder
R6: 2k4 1%; R_1206_3216Metric_Pad1.30x1.75mm_HandSolder
R7: 0; R_1206_3216Metric_Pad1.30x1.75mm_HandSolder

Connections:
+3V3: C4.2, C6.2, IC2.23 (VDDD), LED2.2 (A); also elsewhere on the board
/CC1: C8.1, IC2.15 (CC1), J1.A5 (CC1)
/CC2: C9.1, IC2.14 (CC2), J1.B5 (CC2)
/D+: IC2.17 (D+), J1.A6 (DP1), J1.B6 (DP2)
/D-: IC2.16 (D-), J1.A7 (DN1), J1.B7 (DN2)
/FAULT: IC2.9 (FAULT), LED1.2 (A)
/G_Q: D2.2 (A), Q1.1 (G), Q2.1 (G), R5.2, R7.1
FLIP: IC2.10 (FLIP); also elsewhere on the board
GND: C1.2, C3.2, C4.1, C6.1, C7.2, C8.2, C9.2, C12.2, C13.2, D3.2 (A), D4.2 (A), IC2.19 (GND_1), IC2.22 (GND_2), IC2.25 (GND_3), J1.A1 (GND_1), J1.A12 (GND_2), J1.B1 (GND_3), J1.B12 (GND_4), R6.2, R28.2; also elsewhere on the board
GPIO: IC2.8 (GPIO_1); also elsewhere on the board
HPI_INT: IC2.7 (HPI_INT); also elsewhere on the board
ISINKC: IC2.5 (ISNK_COARSE); also elsewhere on the board
ISINKF: IC2.6 (ISNK_FINE); also elsewhere on the board
unnamed: C2.2, R3.1, R4.2, R7.2
unnamed: D2.1 (K), Q1.3 (D), Q2.3 (D), R5.1
unnamed: IC2.3 (VBUS_FET_EN), R3.2
unnamed: C7.1, IC2.24 (VCCD)
unnamed: LED1.1 (K), R6.1
unnamed: LED2.1 (K), R28.1
SCL: IC2.13 (HPI_SCL); also elsewhere on the board
SDA: IC2.12 (HPI_SDA); also elsewhere on the board
VBMAX: IC2.2 (VBUS_MAX); also elsewhere on the board
VBMIN: IC2.1 (VBUS_MIN); also elsewhere on the board
VBUS: C3.1, C12.1, D4.1 (K), IC2.11 (VDC_OUT), Q2.2 (S); also elsewhere on the board
VPBnk: C1.1, C2.1, C13.1, D3.1 (K), IC2.18 (VBUS_IN), J1.A4 (VBUS_1), J1.A9 (VBUS_2), J1.B4 (VBUS_3), J1.B9 (VBUS_4), Q1.2 (S), R4.1; also elsewhere on the board

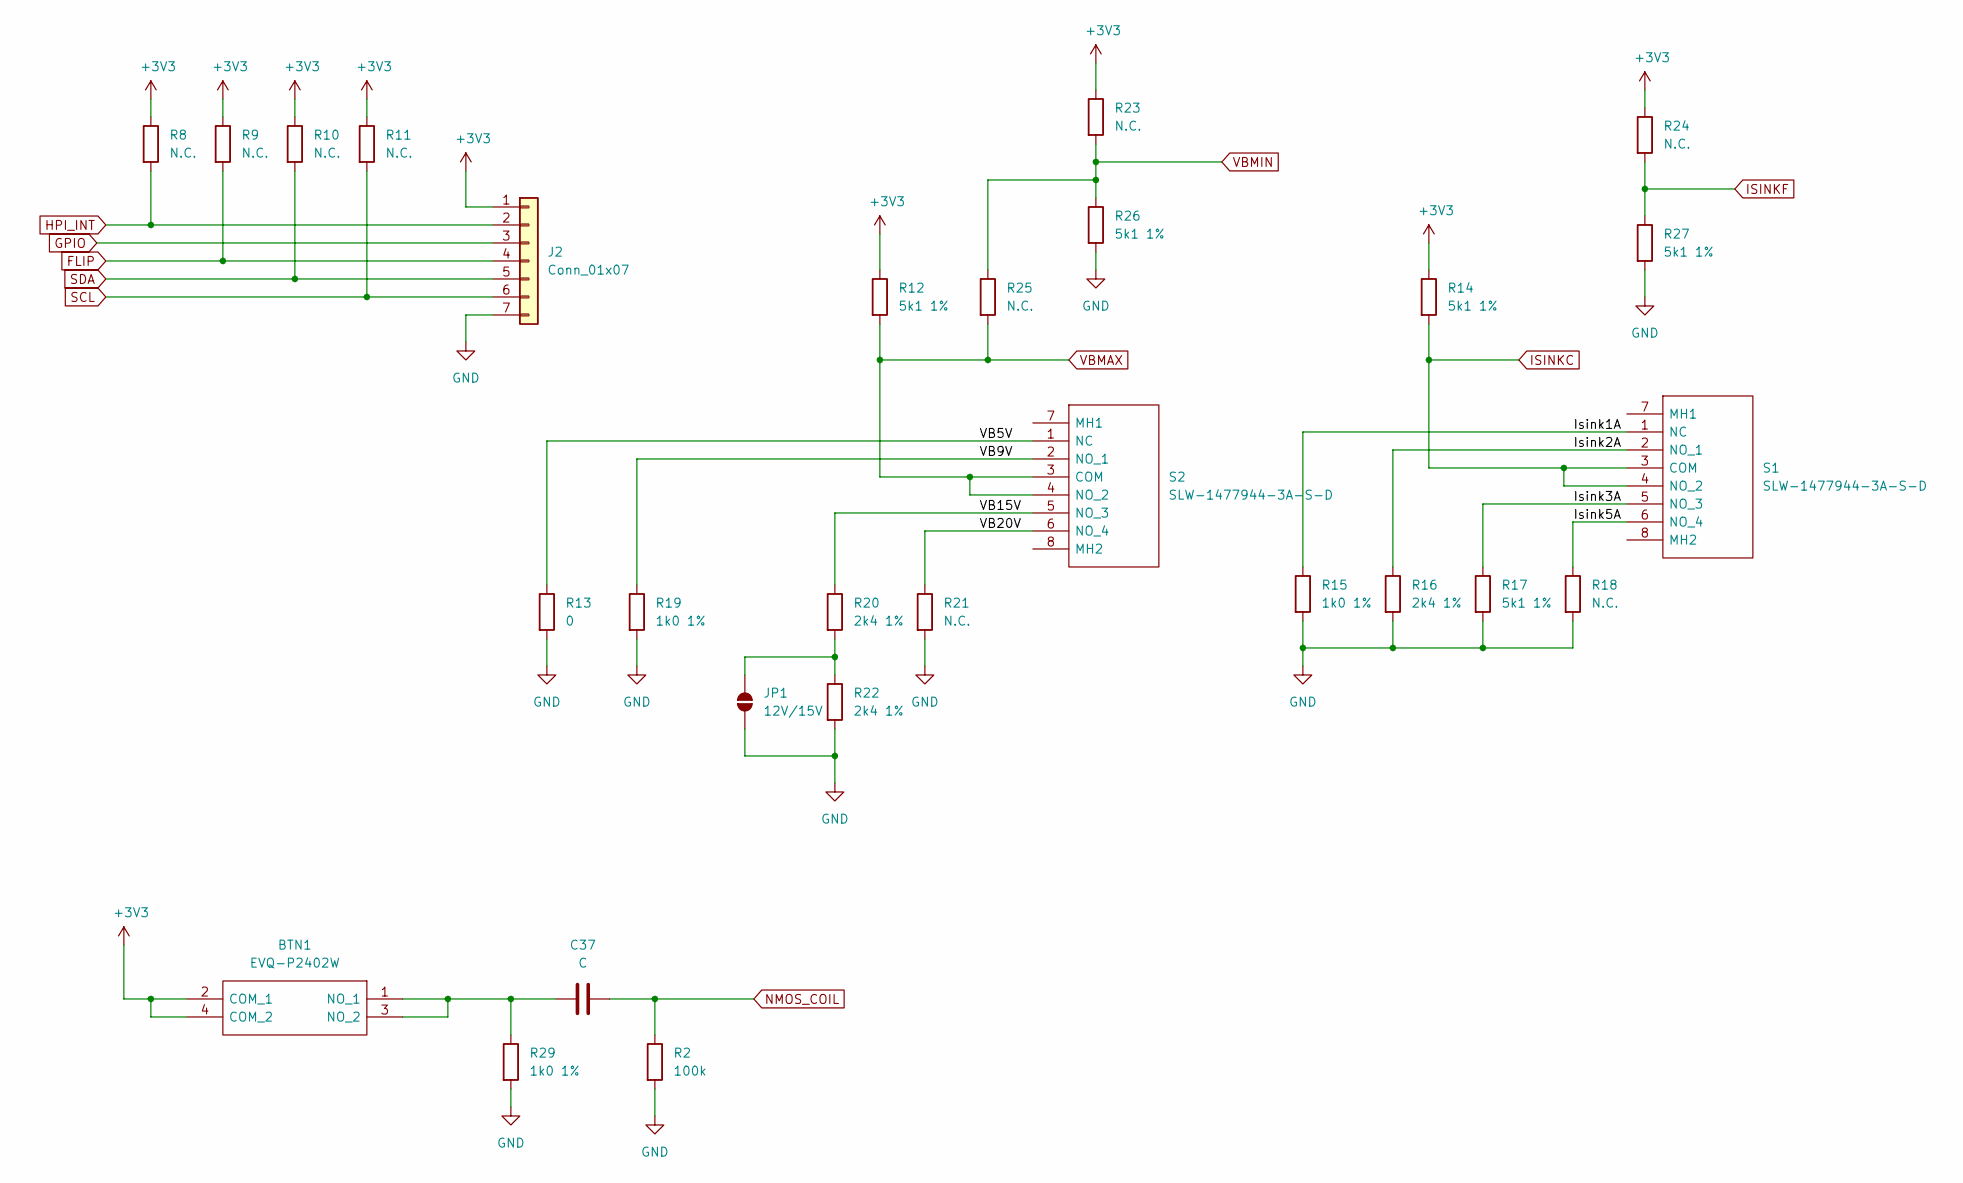
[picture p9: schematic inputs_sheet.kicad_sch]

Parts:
BTN1: EVQ-P2402W; EVQP2402W; Manufacturer_Part_Number EVQ-P2402W; Mouser Part Number 667-EVQ-P2402W
C37: C; C_1206_3216Metric_Pad1.33x1.80mm_HandSolder
J2: Conn_01x07; PinHeader_1x07_P2.54mm_Vertical
JP1: 12V/15V; SolderJumper-2_P1.3mm_Open_RoundedPad1.0x1.5mm
R2: 100k; R_1206_3216Metric_Pad1.30x1.75mm_HandSolder
R8, R9, R10, R11, R18, R21, R23, R24, R25: N.C.; R_1206_3216Metric_Pad1.30x1.75mm_HandSolder
R12, R14, R17, R26, R27: 5k1 1%; R_1206_3216Metric_Pad1.30x1.75mm_HandSolder
R13: 0; R_1206_3216Metric_Pad1.30x1.75mm_HandSolder
R15, R19, R29: 1k0 1%; R_1206_3216Metric_Pad1.30x1.75mm_HandSolder
R16, R20, R22: 2k4 1%; R_1206_3216Metric_Pad1.30x1.75mm_HandSolder
S1, S2: SLW-1477944-3A-S-D; SLW14779443ASD; Manufacturer_Part_Number SLW-1477944-3A-S-D; Mouser Part Number 179-SLW14779443ASD

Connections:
+3V3: BTN1.2 (COM_1), BTN1.4 (COM_2), J2.1, R8.1, R9.1, R10.1, R11.1, R12.1, R14.1, R23.1, R24.1; also elsewhere on the board
/inputs/Isink1A: R15.1, S1.1 (NC)
/inputs/Isink2A: R16.1, S1.2 (NO_1)
/inputs/Isink3A: R17.1, S1.5 (NO_3)
/inputs/Isink5A: R18.1, S1.6 (NO_4)
/inputs/VB5V: R13.1, S2.1 (NC)
/inputs/VB9V: R19.1, S2.2 (NO_1)
/inputs/VB15V: R20.1, S2.5 (NO_3)
/inputs/VB20V: R21.1, S2.6 (NO_4)
FLIP: J2.4, R9.2; also elsewhere on the board
GND: J2.7, JP1.1 (A), R2.2, R13.2, R15.2, R16.2, R17.2, R18.2, R19.2, R21.2, R22.2, R26.2, R27.2, R29.2; also elsewhere on the board
GPIO: J2.3; also elsewhere on the board
HPI_INT: J2.2, R8.2; also elsewhere on the board
ISINKC: R14.2, S1.3 (COM), S1.4 (NO_2); also elsewhere on the board
ISINKF: R24.2, R27.1; also elsewhere on the board
NMOS_COIL: C37.2, R2.1; also elsewhere on the board
unnamed: BTN1.1 (NO_1), BTN1.3 (NO_2), C37.1, R29.1
unnamed: JP1.2 (B), R20.2, R22.1
SCL: J2.6, R11.2; also elsewhere on the board
SDA: J2.5, R10.2; also elsewhere on the board
VBMAX: R12.2, R25.2, S2.3 (COM), S2.4 (NO_2); also elsewhere on the board
VBMIN: R23.2, R25.1, R26.1; also elsewhere on the board

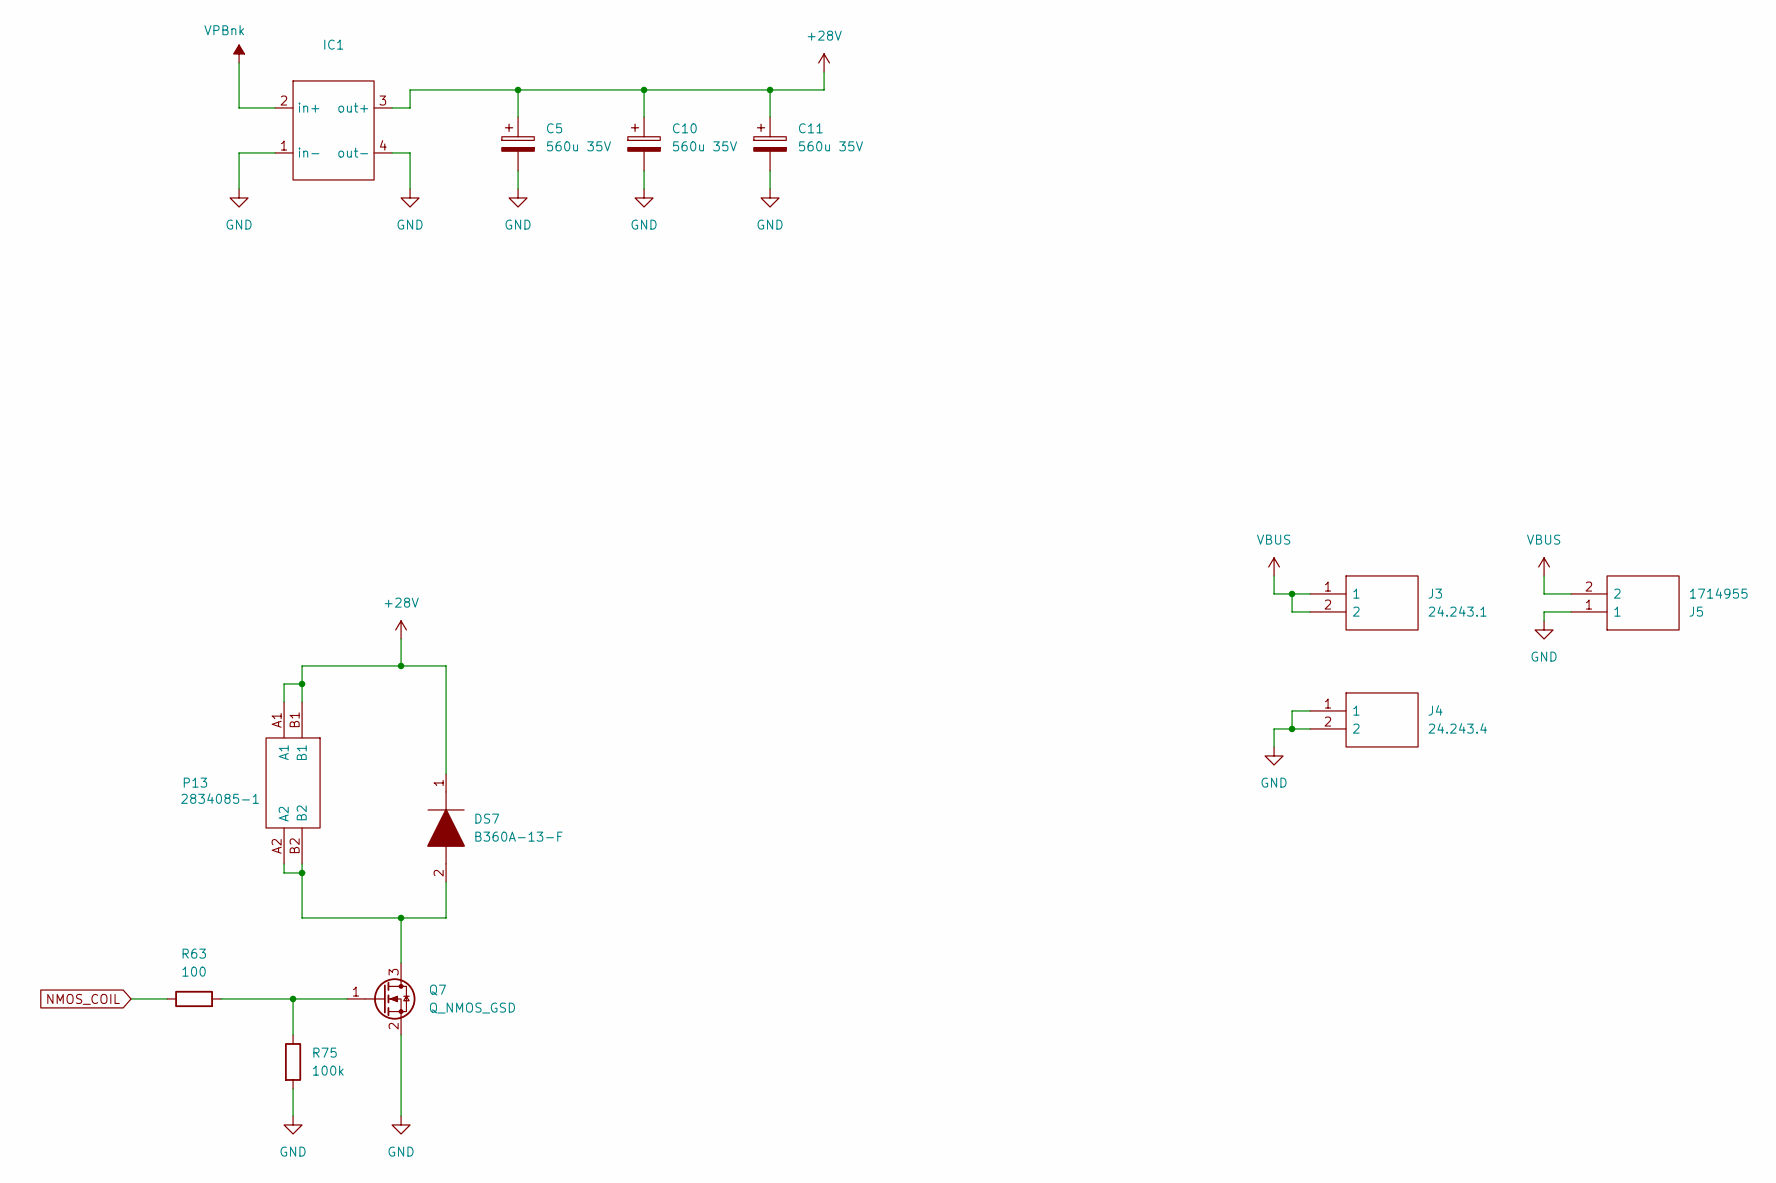
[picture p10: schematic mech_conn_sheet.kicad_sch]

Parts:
C5, C10, C11: 560u 35V; CP_Elec_10x10.5
DS7: B360A-13-F; DIOM5226X240N; Manufacturer_Part_Number B360A-13-F; Mouser Part Number 621-B360A-F
IC1: XL6009_boost
J3: 24.243.1; 242431; Manufacturer_Part_Number 24.243.1
J4: 24.243.4; 242434; Manufacturer_Part_Number 24.243.4
J5: 1714955; Manufacturer_Part_Number 1714955; Mouser Part Number 651-1714955
P13: 2834085-1; 28340851; Manufacturer_Part_Number 2834085-1; Mouser Part Number 571-2834085-1
Q7: Q_NMOS_GSD; SOT-23-3
R63: 100; R_1206_3216Metric_Pad1.30x1.75mm_HandSolder
R75: 100k; R_1206_3216Metric_Pad1.30x1.75mm_HandSolder

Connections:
+28V: C5.1, C10.1, C11.1, DS7.1, IC1.3 (out+), P13.A1, P13.B1
GND: C5.2, C10.2, C11.2, IC1.1 (in-), IC1.4 (out-), J4.1, J4.2, J5.1, Q7.2 (S), R75.2; also elsewhere on the board
NMOS_COIL: R63.1; also elsewhere on the board
unnamed: DS7.2, P13.A2, P13.B2, Q7.3 (D)
unnamed: Q7.1 (G), R63.2, R75.1
VBUS: J3.1, J3.2, J5.2; also elsewhere on the board
VPBnk: IC1.2 (in+); also elsewhere on the board

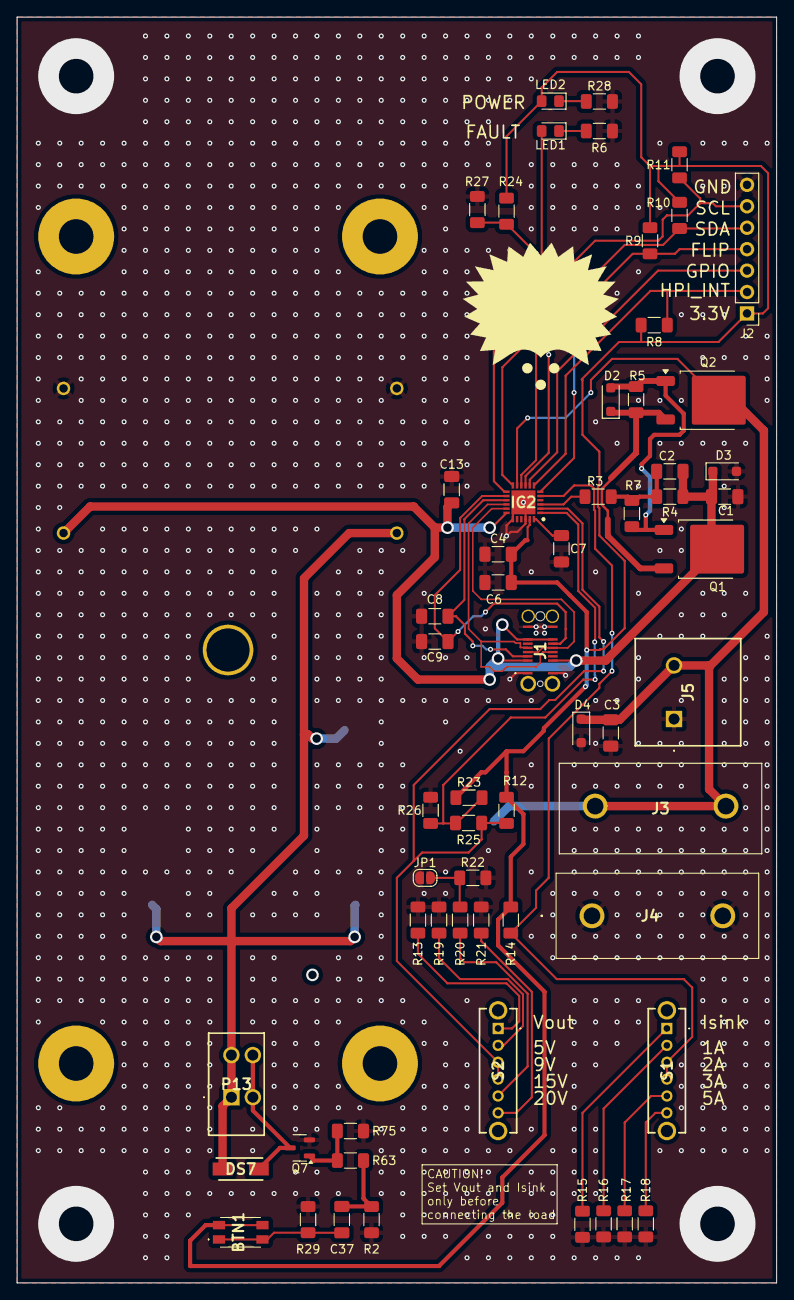
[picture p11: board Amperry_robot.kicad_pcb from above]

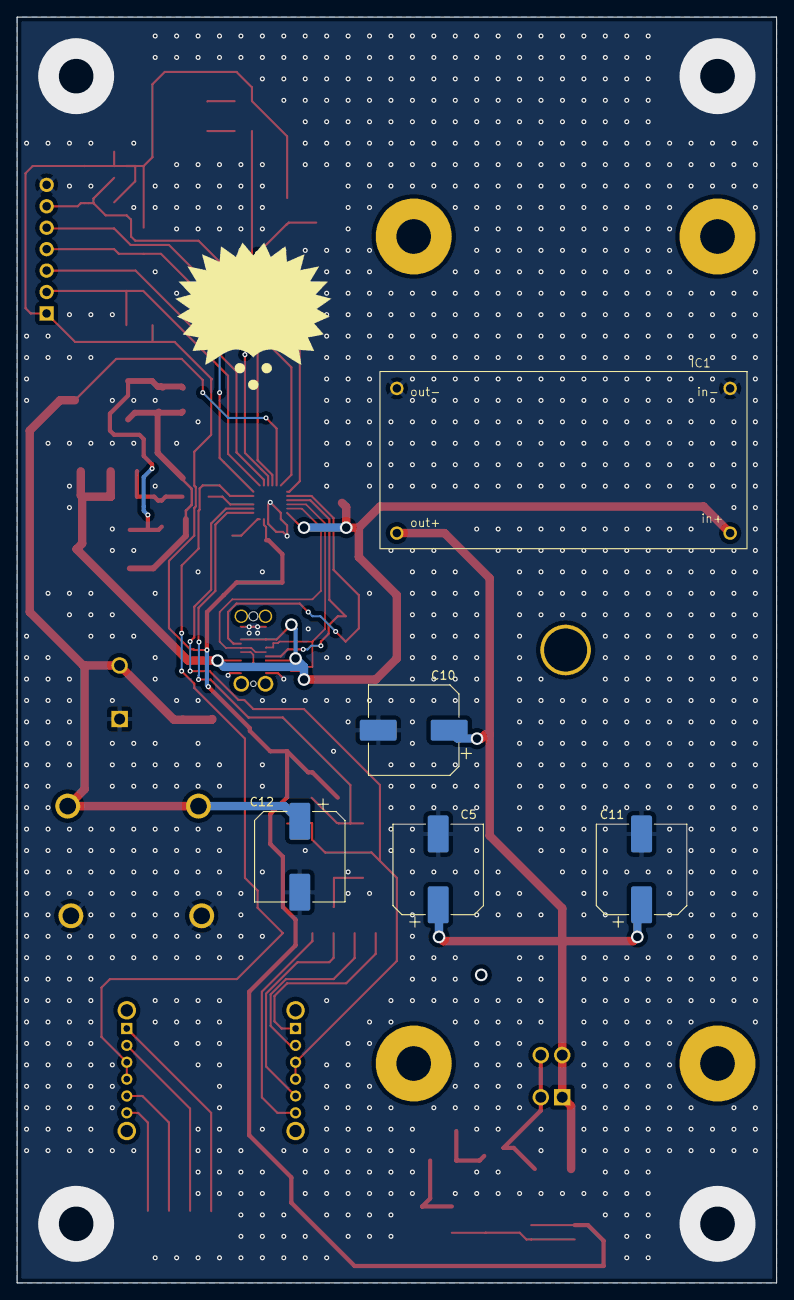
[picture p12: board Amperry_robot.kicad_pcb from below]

Board: 2 copper layers, 90.0 x 150.0 mm, 65 parts (4 on the bottom side), 39 nets.

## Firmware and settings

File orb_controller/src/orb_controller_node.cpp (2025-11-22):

#include <ros/ros.h>
#include <std_msgs/Header.h>
#include "orb_controller/ezpd_bcr_i2c.h"
#include "orb_controller/PowerStatus.h"
#include "orb_controller/PDStatus.h"
#include "orb_controller/SetVoltageCurrent.h"
#include "orb_controller/GetStatus.h"
#include "orb_controller/RequestPDRole.h"

class ORBControllerNode {
public:
    ORBControllerNode() : nh_("~") {
        // Get parameters from ROS parameter server
        int i2c_bus;
        int i2c_addr;
        double publish_rate;
        
        nh_.param("i2c_bus", i2c_bus, 1);
        nh_.param("i2c_address", i2c_addr, 0x08);
        nh_.param("publish_rate", publish_rate, 10.0);
        
        // Initialize I2C interface
        i2c_interface_ = std::make_unique<EZPD_BCR_I2C>(i2c_bus, static_cast<uint8_t>(i2c_addr));
        
        if (!i2c_interface_->initialize()) {
            ROS_ERROR("Failed to initialize I2C interface: %s", i2c_interface_->getLastError().c_str());
            ros::shutdown();
            return;
        }
        
        ROS_INFO("Successfully initialized I2C interface on bus %d, address 0x%02X", i2c_bus, i2c_addr);
        
        // Setup publishers
        power_status_pub_ = nh_.advertise<orb_controller::PowerStatus>("power_status", 10);
        pd_status_pub_ = nh_.advertise<orb_controller::PDStatus>("pd_status", 10);
        
        // Setup services
        set_voltage_current_srv_ = nh_.advertiseService("set_voltage_current", 
            &ORBControllerNode::setVoltageCurrentCallback, this);
        get_status_srv_ = nh_.advertiseService("get_status", 
            &ORBControllerNode::getStatusCallback, this);
        request_pd_role_srv_ = nh_.advertiseService("request_pd_role", 
            &ORBControllerNode::requestPDRoleCallback, this);
        
        // Setup timer for periodic status publishing
        status_timer_ = nh_.createTimer(ros::Duration(1.0/publish_rate), 
            &ORBControllerNode::statusTimerCallback, this);
        
        ROS_INFO("ORB Controller Node initialized successfully");
    }
    
    ~ORBControllerNode() {
        ROS_INFO("Shutting down ORB Controller Node");
    }
    
private:
    void statusTimerCallback(const ros::TimerEvent& event) {
        publishPowerStatus();
        publishPDStatus();
    }
    
    void publishPowerStatus() {
        orb_controller::PowerStatus msg;
        msg.header.stamp = ros::Time::now();
        msg.header.frame_id = "orb_controller";
        
        // Read voltage and current from the chip
        uint16_t voltage_mv, current_ma;
        uint8_t pd_status;
        
        if (i2c_interface_->getVoltageStatus(voltage_mv)) {
            msg.voltage_mv = voltage_mv;
        } else {
            ROS_WARN_THROTTLE(5, "Failed to read voltage status");
            msg.voltage_mv = 0;
        }
        
        if (i2c_interface_->getCurrentStatus(current_ma)) {
            msg.current_ma = current_ma;
        } else {
            ROS_WARN_THROTTLE(5, "Failed to read current status");
            msg.current_ma = 0;
        }
        
        // Calculate power in milliwatts
        msg.power_mw = (static_cast<uint32_t>(msg.voltage_mv) * msg.current_ma) / 1000;
        
        if (i2c_interface_->getPDStatus(pd_status)) {
            msg.pd_active = (pd_status & 0x01) != 0;  // Bit 0 indicates PD active (example)
            msg.pd_profile = (pd_status >> 4) & 0x07; // Bits 4-6 for profile (example)
        } else {
            ROS_WARN_THROTTLE(5, "Failed to read PD status");
            msg.pd_active = false;
            msg.pd_profile = 0;
        }
        
        power_status_pub_.publish(msg);
    }
    
    void publishPDStatus() {
        orb_controller::PDStatus msg;
        msg.header.stamp = ros::Time::now();
        msg.header.frame_id = "orb_controller";
        
        uint8_t pd_status, port_status;
        
        if (i2c_interface_->getPDStatus(pd_status)) {
            msg.pd_status_raw = pd_status;
            
            // Parse PD status bits (these are examples - adjust based on actual datasheet)
            msg.pd_contract_active = (pd_status & 0x01) != 0;
            msg.current_profile = (pd_status >> 4) & 0x07;
        } else {
            ROS_WARN_THROTTLE(5, "Failed to read PD status");
            msg.pd_status_raw = 0;
            msg.pd_contract_active = false;
            msg.current_profile = 0;
        }
        
        if (i2c_interface_->getPortStatus(port_status)) {
            msg.port_status_raw = port_status;
            
            // Parse port status bits (example - adjust based on datasheet)
            msg.type_c_connected = (port_status & 0x01) != 0;
        } else {
            ROS_WARN_THROTTLE(5, "Failed to read port status");
            msg.port_status_raw = 0;
            msg.type_c_connected = false;
        }
        
        // Get negotiated values
        uint16_t voltage_mv, current_ma;
        if (i2c_interface_->getVoltageStatus(voltage_mv)) {
            msg.negotiated_voltage_mv = voltage_mv;
        } else {
            msg.negotiated_voltage_mv = 0;
        }
        
        if (i2c_interface_->getCurrentStatus(current_ma)) {
            msg.negotiated_current_ma = current_ma;
        } else {
            msg.negotiated_current_ma = 0;
        }
        
        pd_status_pub_.publish(msg);
    }
    
    bool setVoltageCurrentCallback(orb_controller::SetVoltageCurrent::Request& req,
                                    orb_controller::SetVoltageCurrent::Response& res) {
        ROS_INFO("Setting voltage to %d mV, current to %d mA", req.voltage_mv, req.current_ma);
        
        if (i2c_interface_->setVoltageCurrent(req.voltage_mv, req.current_ma)) {
            res.success = true;
            res.message = "Successfully set voltage and current";
            ROS_INFO("Successfully set voltage and current");
        } else {
            res.success = false;
            res.message = i2c_interface_->getLastError();
            ROS_ERROR("Failed to set voltage and current: %s", res.message.c_str());
        }
        
        return true;
    }
    
    bool getStatusCallback(orb_controller::GetStatus::Request& req,
                          orb_controller::GetStatus::Response& res) {
        uint16_t voltage_mv, current_ma;
        uint8_t pd_status, port_status;
        
        bool success = true;
        
        if (i2c_interface_->getVoltageStatus(voltage_mv)) {
            res.voltage_mv = voltage_mv;
        } else {
            res.voltage_mv = 0;
            success = false;
        }
        
        if (i2c_interface_->getCurrentStatus(current_ma)) {
            res.current_ma = current_ma;
        } else {
            res.current_ma = 0;
            success = false;
        }
        
        res.power_mw = (static_cast<uint32_t>(res.voltage_mv) * res.current_ma) / 1000;
        
        if (i2c_interface_->getPDStatus(pd_status)) {
            res.pd_status_raw = pd_status;
            res.pd_active = (pd_status & 0x01) != 0;
            res.pd_profile = (pd_status >> 4) & 0x07;
        } else {
            res.pd_status_raw = 0;
            res.pd_active = false;
            res.pd_profile = 0;
            success = false;
        }
        
        if (i2c_interface_->getPortStatus(port_status)) {
            res.port_status_raw = port_status;
        } else {
            res.port_status_raw = 0;
            success = false;
        }
        
        res.success = success;
        if (success) {
            res.message = "Status retrieved successfully";
        } else {
            res.message = "Some status values could not be read: " + i2c_interface_->getLastError();
        }
        
        return true;
    }
    
    bool requestPDRoleCallback(orb_controller::RequestPDRole::Request& req,
                               orb_controller::RequestPDRole::Response& res) {
        ROS_INFO("Requesting PD profile %d", req.profile);
        
        if (req.profile < 1 || req.profile > 5) {
            res.success = false;
            res.message = "Invalid profile. Must be 1-5 (1=5V, 2=9V, 3=12V, 4=15V, 5=20V)";
            ROS_ERROR("%s", res.message.c_str());
            return true;
        }
        
        if (i2c_interface_->requestPDRole(req.profile)) {
            res.success = true;
            res.message = "Successfully requested PD profile";
            ROS_INFO("Successfully requested PD profile %d", req.profile);
        } else {
            res.success = false;
            res.message = i2c_interface_->getLastError();
            ROS_ERROR("Failed to request PD profile: %s", res.message.c_str());
        }
        
        return true;
    }
    
private:
    ros::NodeHandle nh_;
    std::unique_ptr<EZPD_BCR_I2C> i2c_interface_;
    
    ros::Publisher power_status_pub_;
    ros::Publisher pd_status_pub_;
    
    ros::ServiceServer set_voltage_current_srv_;
    ros::ServiceServer get_status_srv_;
    ros::ServiceServer request_pd_role_srv_;
    
    ros::Timer status_timer_;
};

int main(int argc, char** argv) {
    ros::init(argc, argv, "orb_controller_node");
    
    try {
        ORBControllerNode node;
        ros::spin();
    } catch (const std::exception& e) {
        ROS_ERROR("Exception in ORB Controller Node: %s", e.what());
        return 1;
    }
    
    return 0;
}

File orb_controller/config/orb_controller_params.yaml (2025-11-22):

# ORB Controller Configuration Parameters

# I2C Interface Configuration
i2c_bus: 1              # I2C bus number (e.g., 1 for /dev/i2c-1)
i2c_address: 0x08       # I2C device address of EZ-PD BCR chip (CYPD3177)
                        # Default is 0x08, but can be changed via ADDR pins on the chip

# Publishing Rate
publish_rate: 10.0      # Rate in Hz for publishing status messages

# Power Delivery (PD) Profiles
# Profile mapping for standard USB-PD voltages
pd_profiles:
  - profile: 1
    voltage_mv: 5000    # 5V
    max_current_ma: 3000
  - profile: 2
    voltage_mv: 9000    # 9V
    max_current_ma: 3000
  - profile: 3
    voltage_mv: 12000   # 12V
    max_current_ma: 3000
  - profile: 4
    voltage_mv: 15000   # 15V
    max_current_ma: 3000
  - profile: 5
    voltage_mv: 20000   # 20V
    max_current_ma: 5000

# Safety Limits
max_voltage_mv: 20000   # Maximum allowed voltage in millivolts
max_current_ma: 5000    # Maximum allowed current in milliamps
max_power_mw: 100000    # Maximum allowed power in milliwatts (100W)

# Monitoring Thresholds
voltage_tolerance_percent: 5    # Voltage tolerance for warning (%)
current_warning_threshold_ma: 4500  # Current warning threshold in milliamps
temp_warning_threshold_c: 70    # Temperature warning threshold in Celsius (if supported)

# Debug Settings
debug_mode: false       # Enable debug logging
log_raw_registers: false # Log raw register values

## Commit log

2025-09-12 Added first version of lander
    [LANDER-BOM.xlsx]
2025-10-15 updated design, solving hw bugs and updating labels and documentation
    [LANDER-BOM.xlsx]
2025-10-19 First implementation of the ros2 and raspberry-pi usage.
    [LANDER_BOM_Standardized.csv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]
2025-10-19 Remove obsolete BOM and Gerber files for Amperry 2 module power bank project.
    [LANDER-BOM.xlsx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]
2025-10-31 Updated KiCad project files and documentation
    [LANDER_BOM.csv, LANDER_BOM_Standardized.csv, lander_pick_and_place.csv]
2025-11-02 Update README.md with new image paths, enhance documentation for KiCad usage, and add contribution guidelines. Remove obsolete .DS_Store file and include new images for the ORB project.
    [Amperry_robot-B_Cu.gbr, Amperry_robot-B_Mask.gbr, Amperry_robot-B_Paste.gbr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]
2025-11-02 Remove obsolete files and documentation for the Amperry robot project, including all KiCad design files, images, and generated outputs. This cleanup ensures the repository is up-to-date and free of u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
    [Amperry_robot-B_Cu.gbr, Amperry_robot-B_Mask.gbr, Amperry_robot-B_Paste.gbr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]
2025-11-02 Enhance LICENSE.md with additional restrictions for ORB hardware usage and update README.md to reference complete license details. Improve contribution guidelines for CAD file management to maintain 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
2025-11-22 Add battery charging guide with temporary procedure
    [orb_controller_params.yaml]
